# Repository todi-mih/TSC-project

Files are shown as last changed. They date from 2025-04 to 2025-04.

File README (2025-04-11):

Project for E-book made in fusion

Diagrama:
(its in the images folder)

_______
Hardware Modules Overview
ESP32-C6-WROOM-1-N8 – Core Microcontroller
Power Supply: 3.3V
Communication Protocols: SPI, I2C, UART, GPIO
Pin Mapping: Below, each module's interface is connected to the respective microcontroller pins.

USB-C Connector + ESD Protection
Main input for power and data transfer
TVS diodes included for electrostatic discharge (ESD) protection

LiPo Battery Fuel Gauge
Built-In charging controller
IC: MAX17048G+T10 for battery level monitoring
I2C Interface: SCL/SDA for communication with the Battery ChargeLevel IC
Qwiic / Stemma QT Connector for communication via I2C

Reset and Boot Buttons
BOOT: IO9
RESET: EN (Enable)
Reverse polarity protection diodes for safety

LDO Voltage Regulator
Converts 5V to 3.3V, providing power to the ESP32-C6 and connected peripherals

External Flash - NOR Flash 64MB
Connection Type: SPI
FLASH_CS: IO11
Shared SPI Lines: MOSI, MISO, SCK (with SD card and e-paper)

Environmental Sensor - BME688
Protocol: I2C (shared with RTC)
Voltage Supply: 3.3V
Pin Assignments: SDA, SCL

E-Paper Display
Connection Type: SPI
EPD_CS: IO10
EPD_DC: IO5
EPD_RST: IO23
EPD_BUSY: IO3
Shared SPI Lines: MOSI, SCK with SD Card

RTC Module - DS3231SN
Connection Type: I2C
SCL: IO22
SDA: IO21
INT_RTC: IO8
32KHZ: IO1
RTC_RST: IO18

SD Card Interface
Connection Type: SPI
SS_SD: IO4
MOSI: IO7
MISO: IO2
SCK: IO6

SPI Line Protection
Safeguards the SPI communication lines used by external modules like the SD card, e-paper display, and external flash
______

ESP32-C6 PINS
Protocol	ESP32-C6 Assigned Pins		Attached Devices
USB				GPIO13, GPIO12			Power supply & host communication
I2C				GPIO22, GPIO24			Environmental sensor (BME688), RTC, Battery voltage monitor
SPI			  GPIO7, GPIO2, GPIO6		E-paper display, NOR flash memory, SD storage
UART			GPIO16, GPIO17			Debugging / Firmware change
GPIO			GPIO0...GPIO23			Buttons, indicator outputs

BOM , links , datasheets
BUTTON_CUSYOMV1 https://eu.mouser.com/ProductDetail/Omron-Electronics/B3F-1000S?qs=C6KiJco3hx0Z3qfxWTJOrg%3D%3D
https://eu.mouser.com/datasheet/2/307/en_b3f-13826.pdf

100nF capacitor https://store.comet.srl.ro/Catalogue/Product/48939/ https://store.comet.bg/download-file.php?id=11
CPH3225A        https://eu.mouser.com/ProductDetail/Seiko-Semiconductors/CPH3225Aqs=3etwrb1wR%252BhUOph6lAO7eg%3D%3D
https://ro.mouser.com/datasheet/2/360/Seiko_Instruments_MicroBattery_E_20230330_2024Jan_-3561061.pdf
1.7uF capacitor https://store.comet.srl.ro/Catalogue/Product/5163462/ https://store.comet.bg/download-file.php?id=25117
USBLC6-2SC6Y    https://eu.mouser.com/ProductDetail/STMicroelectronics/USBLC6-2SC6Yqs=gNDSiZmRJS%2FOgDexvXkdow%3D%3D
https://ro.mouser.com/datasheet/2/389/usblc6_2sc6y-1852505.pdf
PGB1010603MR    https://eu.mouser.com/ProductDetail/Littelfuse/PGB1010603MR?qs=gu7KAQ731URLg4GSnNNN7Q%3D%3D
https://www.littelfuse.com/assetdocs/pulseguard-esd-suppressors-pgb1-datasheet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
MBR0530         https://eu.mouser.com/ProductDetail/onsemi/MBR0530T3G?qs=3JMERSakebpEmdUS6GetdQ%3D%3D
https://www.littelfuse.com/assetdocs/pulseguard-esd-suppressors-pgb1-datasheet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
TP20R           https://eu.mouser.com/ProductDetail/KOA-Speer/RN73R1ETTP20R0D50?qs=vLWxofP3U2xF4IfSiw9UAw%3D%3D
DS3231SN#       https://eu.mouser.com/ProductDetail/Analog-Devices-Maxim-Integrated/DS3231SN?qs=1eQvB6Dk1vhUlr8%2FOrV0Fw%3D%3D
https://www.koaspeer.com/pdfs/RN73R.pdf
W25Q512JVEIQ    https://eu.mouser.com/ProductDetail/Winbond/W25Q512JVEIQ?qs=l7cgNqFNU1jw6svr3at6tA%3D%3D
https://ro.mouser.com/datasheet/2/949/Winbond_W25Q512JV_Datasheet-3240039.pdf
MAX17048G+T10   https://eu.mouser.com/ProductDetail/Analog-Devices-Maxim-Integrated/MAX17048G%2bT10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
https://ro.mouser.com/datasheet/2/609/MAX17048_MAX17049-3469099.pdf
USBLC6-2SC6Y    https://eu.mouser.com/ProductDetail/STMicroelectronics/USBLC6-2SC6Y?qs=gNDSiZmRJS%2FOgDexvXkdow%3D%3D
https://ro.mouser.com/datasheet/2/389/usblc6_2sc6y-1852505.pdf
DMG2305UX-7     https://eu.mouser.com/ProductDetail/Diodes-Incorporated/DMG2305UX-7?qs=L1DZKBg7t5F%2FNBHrjfxC%252Bg%3D%3D
https://www.diodes.com/assets/Datasheets/DMG2305UX.pdf
XC6220A331MR-G  https://eu.mouser.com/ProductDetail/Torex-Semiconductor/XC6220A331MR-G?qs=AsjdqWjXhJ8ZSWznL1J0gg%3D%3D
https://ro.mouser.com/datasheet/2/760/xc6220-3371556.pdf
SI1308EDL-T1-BE3  https://eu.mouser.com/ProductDetail/Vishay-Siliconix/SI1308EDL-T1-BE3?qs=zW32dvEIR3shhEGZ2ACCcQ%3D%3D
https://www.vishay.com/doc?63399
MCP73831        https://eu.mouser.com/ProductDetail/Microchip-Technology/MCP73831T-2ACI-OT?qs=yUQqVecv4qvbBQBGbHx0Mw%3D%3D
https://ro.mouser.com/datasheet/2/268/MCP73831_Family_Data_Sheet_DS20001984H-3441711.pdf
ESP32-C6-WROOM-1-N8   https://eu.mouser.com/ProductDetail/Espressif-Systems/ESP32-C6-WROOM-1-N8?qs=8Wlm6%252BaMh8ST02Gmwp74cw%3D%3D
https://ro.mouser.com/datasheet/2/891/Espressif_ESP32_C6_WROOM_1__Datasheet_V0_1_PRELIMI-3239987.pdf
BD5229G     https://eu.mouser.com/ProductDetail/ROHM-Semiconductor/BD5229G-1TR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
https://fscdn.rohm.com/en/products/databook/datasheet/ic/power/voltage_detector/bd52xxg-1-e.pdf
FH34SRJ-24S-0.5SH_99_   https://eu.mouser.com/ProductDetail/Hirose-Connector/FH34SRJ-24S-0.5SH50?qs=iyLo5FA4poC8fzWlavnA7A%3D%3D
https://ro.mouser.com/datasheet/2/185/FH34SRJ_24S_0_5SH_50__CL0580_1255_6_50_2DDrawing_0-1615030.pdf
BME688     https://eu.mouser.com/ProductDetail/Bosch-Sensortec/BME688?qs=IS%252B4QmGtzzqQoVDscqwx3A%3D%3D
https://ro.mouser.com/datasheet/2/783/bst_bme688_fl000-2307034.pdf

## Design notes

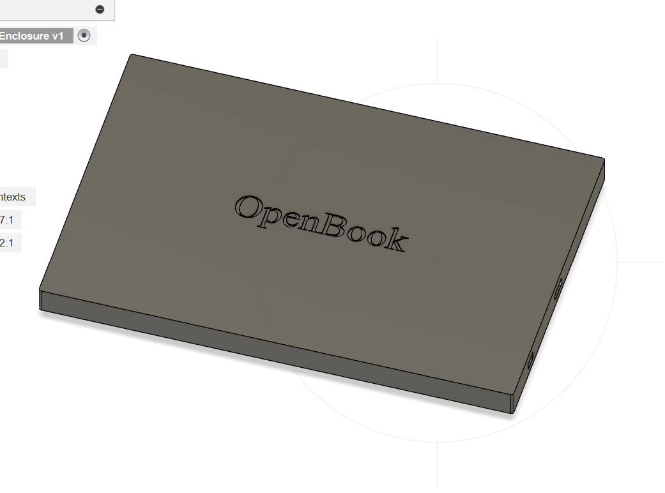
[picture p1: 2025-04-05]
Images/Screenshot 2025-04-05 224908.png

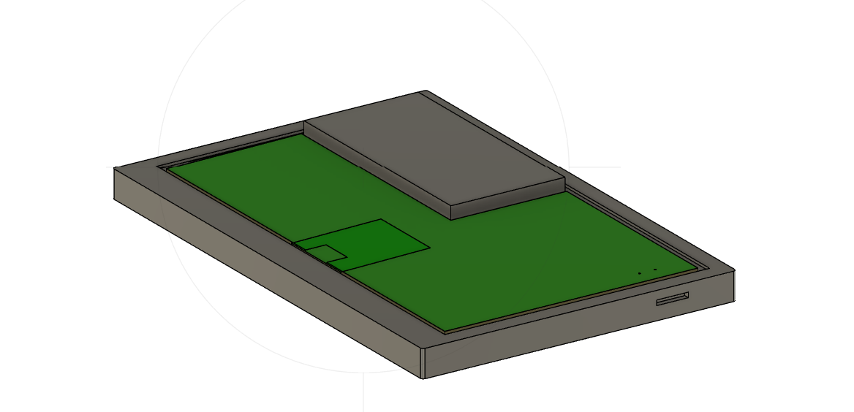
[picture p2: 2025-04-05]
Images/Screenshot 2025-04-05 224919.png

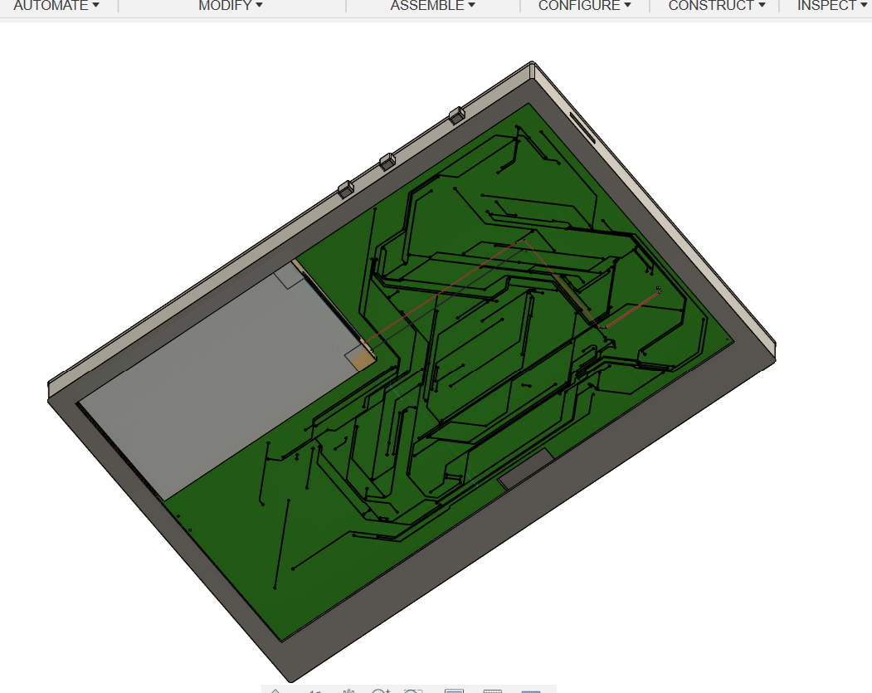
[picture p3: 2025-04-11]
Images/Screenshot 2025-04-11 193749.png

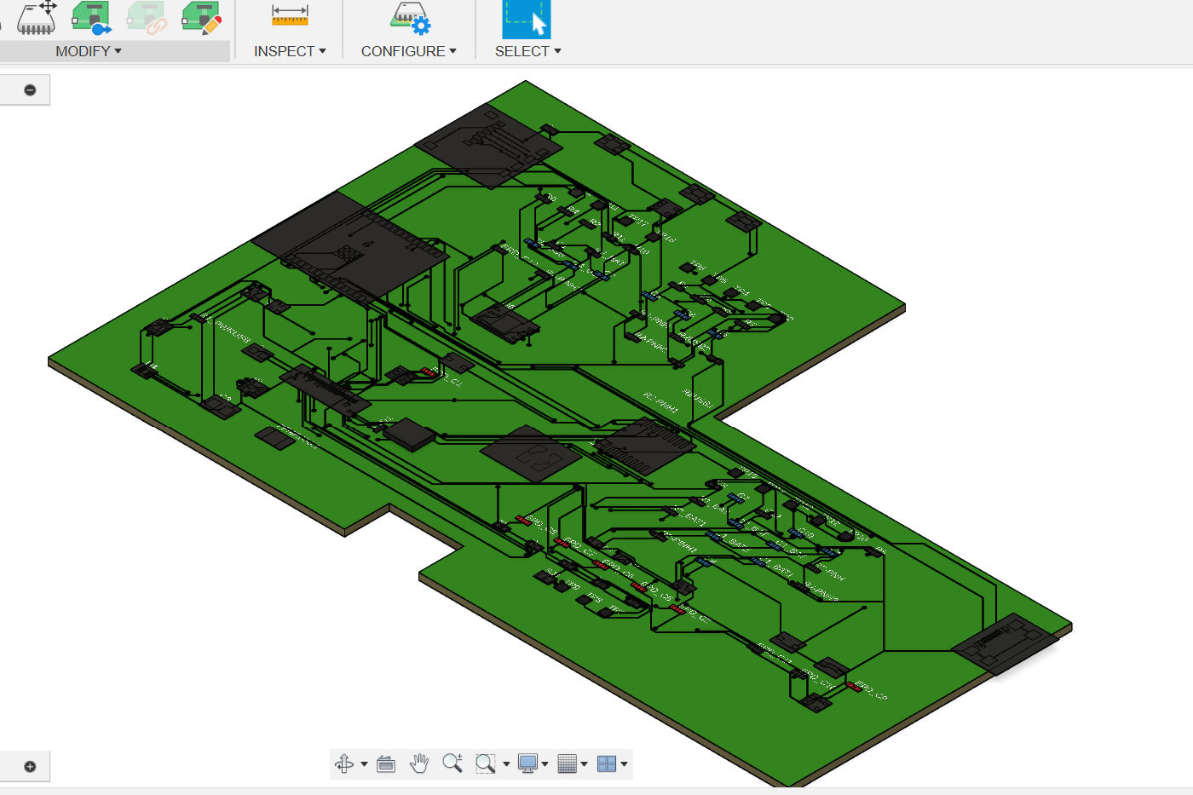
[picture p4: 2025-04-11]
Images/Screenshot 2025-04-11 192457.png

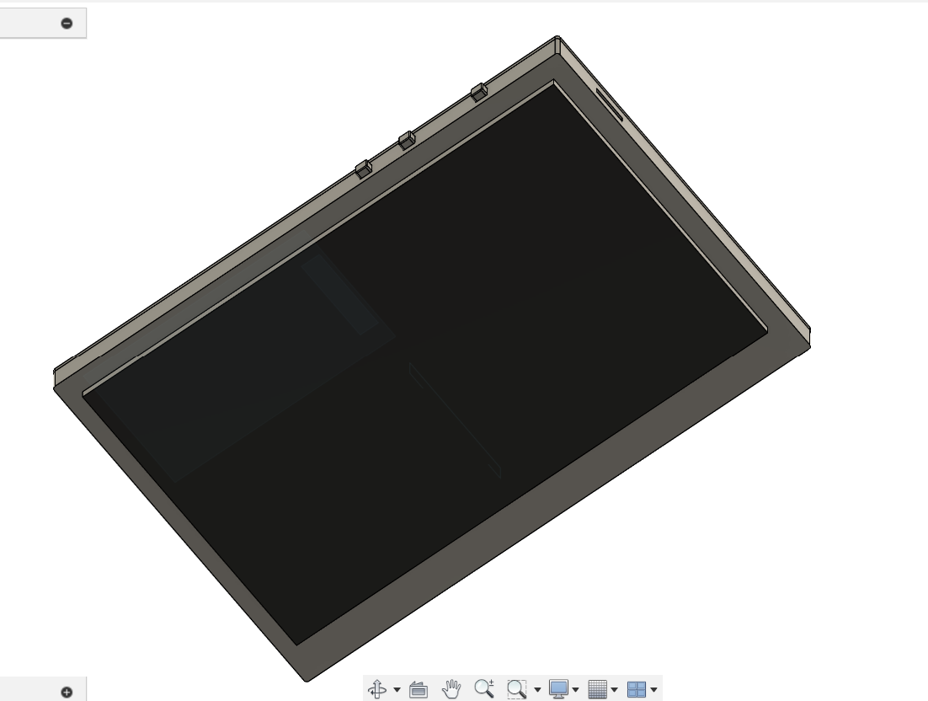
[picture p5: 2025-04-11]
Images/Screenshot 2025-04-11 194323.png

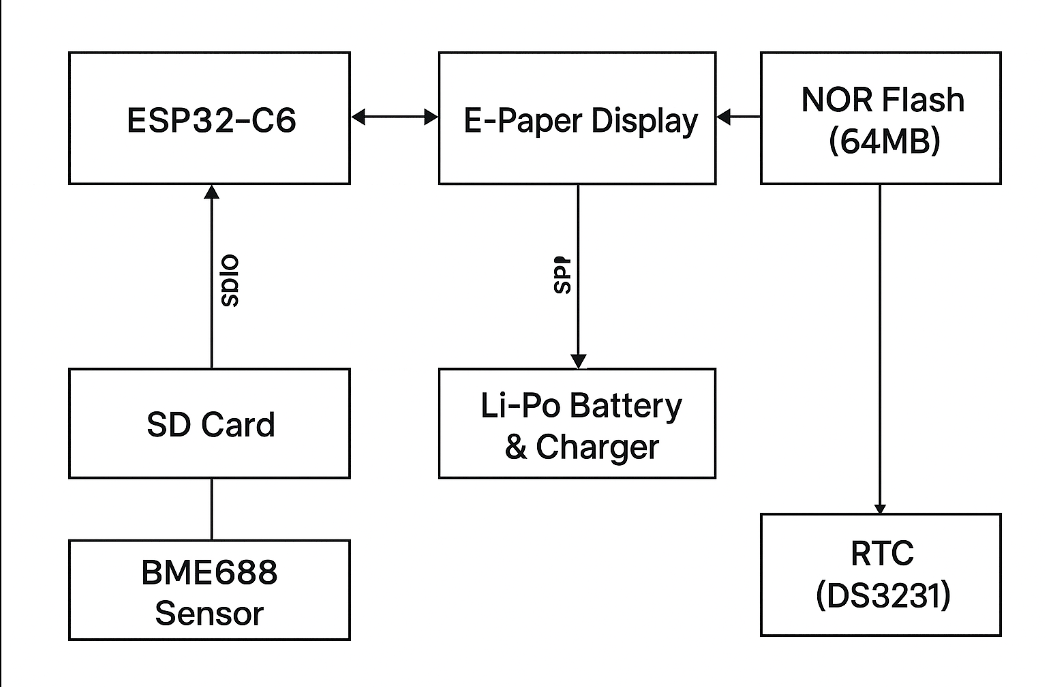
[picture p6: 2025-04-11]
Images/Screenshot 2025-04-11 145103.png

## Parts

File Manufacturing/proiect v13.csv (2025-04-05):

Qty | Value | Device | Package | Parts | Description | ARROW_PART_NUMBER | ARROW_PRICE-STOCK | AVAILABILITY | CENTROID_NOT_SPECIFIED | CHECK_PRICES | COPYRIGHT | DATASHEET | DESCRIPTION | DIGIKEY_DESCRIPTION | DIGIKEY_PART_NUMBER | HEIGHT | LEAD_FREE | MANUFACTURER_NAME | MANUFACTURER_PART_NUMBER | MF | MFR_NAME | MOUSER_PART_NUMBER | MOUSER_PRICE-STOCK | MOUSER_TESTING_PART_NUMBER | MOUSER_TESTING_PRICE-STOCK | MP | MPN | PACKAGE | POPULARITY | PREFIX | PRICE | PROD_ID | PURCHASE-URL | ROHS | SNAPEDA_LINK | SPICEMODEL | SPICEPREFIX | TEMPERATURE_RANGE_HIGH | TEMPERATURE_RANGE_LOW | TP_SIGNAL_NAME | VALUE
1 |  | ADAFRUIT_LEDCHIP-LED0603 | ADAFRUIT_CHIP-LED0603 | LED1 | LED
7 |  | EAGLE-LTSPICE_CC0402 | EAGLE-LTSPICE_C0402 | EPD_C1, EPD_C2, EPD_C5, EPD_C6, EPD_C7, EPD_C8, EPD_C9 | CAPACITOR, European symbol |  |  |  |  |  |  |  |  |  |  |  |  |  |  |  |  |  |  |  |  |  |  |  |  |  |  |  |  |  |  | NONE | C
2 |  | ESP32_WROVER_EAGLE-LTSPICE_CC0402 | ESP32_WROVER_EAGLE-LTSPICE_C0402 | EPD_C10, ERD_C11 | CAPACITOR, European symbol |  |  |  |  |  |  |  |  |  |  |  |  |  |  |  |  |  |  |  |  |  |  |  |  |  |  |  |  |  |  | NONE | C
1 |  | SJ | SJ | SJ1 | SMD solder JUMPER |  |  |  |  |  |  |  |  |  |  |  |  |  |  |  |  |  |  |  |  |  |  |  | 3
1 | 0.47 | ESP32_WROVER_EAGLE-LTSPICE_RR0402 | ESP32_WROVER_EAGLE-LTSPICE_R0402 | R3 | RESISTOR, European symbol |  |  |  |  |  |  |  |  |  |  |  |  |  |  |  |  |  |  |  |  |  |  |  |  |  |  |  |  |  |  | NONE | R
1 | 100 uF TANT | RCL_CPOL-EUCT3528 | RCL_CT3528 | C3 | POLARIZED CAPACITOR, European symbol |  |  |  |  |  |  |  |  |  |  |  |  |  |  |  |  |  |  |  |  |  |  |  | 0 |  |  |  |  |  |  |  | C
3 | 100k | ESP32_WROVER_EAGLE-LTSPICE_RR0402 | ESP32_WROVER_EAGLE-LTSPICE_R0402 | R1_PWRUSB, R2-PINH1, R2-PINH2 | RESISTOR, European symbol |  |  |  |  |  |  |  |  |  |  |  |  |  |  |  |  |  |  |  |  |  |  |  |  |  |  |  |  |  |  | NONE | R
8 | 100nF | EAGLE-LTSPICE_CC0402 | EAGLE-LTSPICE_C0402 | C1, C2, C4_USB, C5, C6, C8, C9, C10 | CAPACITOR, European symbol |  |  |  |  |  |  |  |  |  |  |  |  |  |  |  |  |  |  |  |  |  |  |  |  |  |  |  |  |  |  | NONE | C
1 | 100nF | ESP32_WROVER_EAGLE-LTSPICE_CC0402 | ESP32_WROVER_EAGLE-LTSPICE_C0402 | C12 | CAPACITOR, European symbol |  |  |  |  |  |  |  |  |  |  |  |  |  |  |  |  |  |  |  |  |  |  |  |  |  |  |  |  |  |  | NONE | C
13 | 10k | ESP32_WROVER_EAGLE-LTSPICE_RR0402 | ESP32_WROVER_EAGLE-LTSPICE_R0402 | R1-PNH, R2, R2-PNH, R2-PNH1, R2-PNH2, R2-PNH3, R4, R6, R7, R8, R9, R10, R11 | RESISTOR, European symbol |  |  |  |  |  |  |  |  |  |  |  |  |  |  |  |  |  |  |  |  |  |  |  |  |  |  |  |  |  |  | NONE | R
1 | 10uF | EAGLE-LTSPICE_CC0402 | EAGLE-LTSPICE_C0402 | C7 | CAPACITOR, European symbol |  |  |  |  |  |  |  |  |  |  |  |  |  |  |  |  |  |  |  |  |  |  |  |  |  |  |  |  |  |  | NONE | C
1 | 112A-TAAR-R03_ATTEND | 112A-TAAR-R03_ATTEND | 112ATAARR03ATTEND | J2 | Micro SD Card Socket, Push-Push Type, Top Mount, SMT, H=1.83mm, 10u |  |  |  |  |  |  |  | Micro SD Card Socket | Push-Push Type | Top Mount | SMT | H=1.83mm | 10u |  |  | 1.9mm |  | ATTEND | 112A-TAAR-R03 ATTEND
1 | 15 | ESP32_WROVER_EAGLE-LTSPICE_RR0402 | ESP32_WROVER_EAGLE-LTSPICE_R0402 | R5 | RESISTOR, European symbol |  |  |  |  |  |  |  |  |  |  |  |  |  |  |  |  |  |  |  |  |  |  |  |  |  |  |  |  |  |  | NONE | R
1 | 1uF | ESP32_WROVER_EAGLE-LTSPICE_CC0402 | ESP32_WROVER_EAGLE-LTSPICE_C0402 | ERD_C12 | CAPACITOR, European symbol |  |  |  |  |  |  |  |  |  |  |  |  |  |  |  |  |  |  |  |  |  |  |  |  |  |  |  |  |  |  | NONE | C
1 | 2.2 | ESP32_WROVER_EAGLE-LTSPICE_RR0402 | ESP32_WROVER_EAGLE-LTSPICE_R0402 | R1 | RESISTOR, European symbol |  |  |  |  |  |  |  |  |  |  |  |  |  |  |  |  |  |  |  |  |  |  |  |  |  |  |  |  |  |  | NONE | R
1 | 200 | ESP32_WROVER_EAGLE-LTSPICE_RR0402 | ESP32_WROVER_EAGLE-LTSPICE_R0402 | R1_BAT | RESISTOR, European symbol |  |  |  |  |  |  |  |  |  |  |  |  |  |  |  |  |  |  |  |  |  |  |  |  |  |  |  |  |  |  | NONE | R
2 | 20V/4.2A/52mO/1.4W | ESP32_WROVER_SPARKFUN-DISCRETESEMI_MOSFET_PCH-DMG2305UX-7 | ESP32_WROVER_SPARKFUN-DISCRETESEMI_SOT23-3 | Q1, Q3 | P-channel MOSFETs |  |  |  |  |  |  |  |  |  |  |  |  |  |  |  |  |  |  |  |  |  |  |  |  |  |  | TRAN-14388 |  |  |  |  |  |  |  |  | 20V/4.2A/52mO/1.4W
2 | 2k | ESP32_WROVER_EAGLE-LTSPICE_RR0402 | ESP32_WROVER_EAGLE-LTSPICE_R0402 | R2_BAT, R2_BAT1 | RESISTOR, European symbol |  |  |  |  |  |  |  |  |  |  |  |  |  |  |  |  |  |  |  |  |  |  |  |  |  |  |  |  |  |  | NONE | R
5 | 4.7uF | EAGLE-LTSPICE_CC0402 | EAGLE-LTSPICE_C0402 | C1_BAT, C1_BAT1, C1_BAT2, C2_BAT, C5_USB | CAPACITOR, European symbol |  |  |  |  |  |  |  |  |  |  |  |  |  |  |  |  |  |  |  |  |  |  |  |  |  |  |  |  |  |  | NONE | C
1 | 4.7uF/25V | EAGLE-LTSPICE_CC0402 | EAGLE-LTSPICE_C0402 | C4 | CAPACITOR, European symbol |  |  |  |  |  |  |  |  |  |  |  |  |  |  |  |  |  |  |  |  |  |  |  |  |  |  |  |  |  |  | NONE | C
2 | 5k1 | ESP32_WROVER_EAGLE-LTSPICE_RR0402 | ESP32_WROVER_EAGLE-LTSPICE_R0402 | R2USB1, R2USB2 | RESISTOR, European symbol |  |  |  |  |  |  |  |  |  |  |  |  |  |  |  |  |  |  |  |  |  |  |  |  |  |  |  |  |  |  | NONE | R
1 | 68uH | 744043680IND_4828-WE-TPC_WRE | IND_4828-WE-TPC_WRE | L1 |  |  |  |  |  |  | Copyright (C) 2024 Ultra Librarian. All rights reserved. |  |  |  |  |  |  |  | 744043680 |  | Wurth Electronics
1 | BD5229G-TR | BD5229G-TR | SOT95P280X125-5N | IC2 | Voltage Detector with Adjustable Delay Time: CMOS processes are utilized to develop high precision, low current consumption CMOS reset ICs that allow arbitrary setting of the delay time. The extensive lineup includes both Nch Open Drain and CMOS output types in a wide range of detection voltages (from 2.3V to 6.0V, in 0.1V steps), enabling selection of the ideal solution based on customer requirements. In addition, the entire series is of course both lead-free and RoHS-compliant. |  |  |  |  |  |  |  | Voltage Detector with Adjustable Delay Time: CMOS processes are utilized to develop high precision | low current consumption CMOS reset ICs that allow arbitrary setting of the delay time. The extensive lineup includes both Nch Open Drain and CMOS output types in a wide range of detection voltages (from 2.3V to 6.0V | in 0.1V steps) | enabling selection of the ideal solution based on customer requirements. In addition | the entire series is of course both lead-free and RoHS-compliant. |  |  | 1.25mm |  | ROHM Semiconductor | BD5229G-TR |  |  | 755-BD5229G-TR | https://www.mouser.co.uk/ProductDetail/ROHM-Semiconductor/BD5229G-TR?qs=4kLU8WoGk0vvnhrrYwdszw%3D%3D
3 | BUTTON_CUSYOMV1 | BUTTON_CUSYOMV1 | MYBUTTON | BOOT_BUTTON, CHANGE_BUTTON, RESET_BUTTON
1 | CPH3225A | CPH3225A | CAPCP3225X100N | C11 | Cap 0.011F 3.3V 1210 Flat Check availability |  |  | Not in stock |  | https://www.snapeda.com/parts/CPH3225A/Seiko+Instruments/view-part/?ref=eda |  |  | 11 mF (EDLC) Supercapacitor 3.3 V 1210 (3225 Metric) - - |  |  |  |  |  |  | Seiko Instruments |  |  |  |  |  | CPH3225A |  | 1210 Seiko |  |  | None |  | https://www.snapeda.com/api/url_track_click_mouser/?unipart_id=562593&manufacturer=Seiko Instruments&part_name=CPH3225A&search_term=None |  | https://www.snapeda.com/parts/CPH3225A/Seiko+Instruments/view-part/?ref=snap
1 | DS3231SN# | DS3231SN# | SOIC127P1032X265-16N | U5 | Real Time Clock Serial 16-Pin SOIC W T/R Check availability |  |  | In Stock |  | https://www.snapeda.com/parts/DS3231SN%23/Analog+Devices/view-part/?ref=eda |  |  | Extremely Accurate I²C-Integrated RTC/TCXO/Crystal |  |  |  |  |  |  | Analog Devices |  |  |  |  |  | DS3231SN# |  | SOIC-16 Maxim |  |  | None |  | https://www.snapeda.com/api/url_track_click_mouser/?unipart_id=99048&manufacturer=Analog Devices&part_name=DS3231SN#&search_term=None |  | https://www.snapeda.com/parts/DS3231SN%23/Analog+Devices/view-part/?ref=snap
1 | ESP32-C6-WROOM-1-N8 | ESP32-C6-WROOM-1-N8 | XCVR_ESP32-C6-WROOM-1-N8 | U2 | Check availability |  |  | In Stock |  | https://www.snapeda.com/parts/ESP32-C6-WROOM-1-N8/Espressif+Systems/view-part/?ref=eda |  |  | Multiprotocol Modules ESP32-C6 module | Wi-Fi 6 in 2.4 GHz band | Bluetooth 5 | Zigbee 3.0 and Thread. ESP34-WROOM Compatible - ENGINEERING SAMPLE |  |  |  |  |  |  | Espressif Systems |  |  |  |  |  | ESP32-C6-WROOM-1-N8 |  | None |  |  | None |  |  |  | https://www.snapeda.com/parts/ESP32-C6-WROOM-1-N8/Espressif+Systems/view-part/?ref=snap
1 | ESP32C6_VARISTORCN1812 | ESP32C6_VARISTORCN1812 | ESP32C6_VARISTOR_CT/CN1812 | PFMF.050.1 | VARISTOR |  |  |  |  |  |  |  |  |  |  |  |  |  |  |  |  |  |  |  |  |  |  |  | 0
2 | ESP32_WROVER_AVX---SD0805S020S1R0_AVX_SD0805S020S1R0_0_0AVX_SD0805S020S1R0_0_0 | ESP32_WROVER_AVX---SD0805S020S1R0_AVX_SD0805S020S1R0_0_0AVX_SD0805S020S1R0_0_0 | ESP32_WROVER_AVX---SD0805S020S1R0_AVX_SD0805S020S1R0_0 | D2, D6 | Schottky Barrier Rectifier Diode |  |  |  | No |  |  | http://datasheets.avx.com/schottky.pdf |  | DIODE SCHOTTKY 20V 1A 0805 | 478-7800-1-ND |  | yes |  |  | AVX |  | 581-SD0805S020S1R0 |  |  |  |  |  | 0805 (2012 metric) |  | D |  |  |  | yes |  |  |  | +125°C | -55°C
1 | ESP32_WROVER_BME680_BME680 | ESP32_WROVER_BME680_BME680 | ESP32_WROVER_BME680_PSON80P300X300X100-8N | U3 | Integrated Environmental Unit |  |  | Unavailable |  |  |  |  | Integrated Environmental Unit |  |  |  |  |  |  | Bosch Sensortec |  |  |  |  |  | BME680 |  | LGA-8 Bosch Tools |  |  | None
1 | ESP32_WROVER_SPARKFUN-IC-POWER_MCP73831 | ESP32_WROVER_SPARKFUN-IC-POWER_MCP73831 | ESP32_WROVER_SPARKFUN-IC-POWER_SOT23-5 | U1 | MCP73831T Li-Ion, Li-Pol Controller |  |  |  |  |  |  |  |  |  |  |  |  |  |  |  |  |  |  |  |  |  |  |  |  |  |  | IC-09995
1 | FH34SRJ-24S-0.5SH_99_ | FH34SRJ-24S-0.5SH_99_ | FH34SRJ24S05SH99 | J3 | (0.50mm) Surface Mount, Right Angle |  |  |  |  |  |  |  | 24 Position FFC | FPC Connector Contacts | (0.50mm) Surface Mount | Right Angle |  |  | 1.1mm |  | Hirose | FH34SRJ-24S-0.5SH(99) |  |  | 798-FH34SRJ24S05SH99 | https://www.mouser.co.uk/ProductDetail/Hirose-Connector/FH34SRJ-24S-0.5SH99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
1 | MAX17048G+T10 | MAX17048G+T10 | SON50P200X200X80-9N | U4 | Check availability |  |  | In Stock |  | https://www.snapeda.com/parts/MAX17048G+T10/Analog+Devices/view-part/?ref=eda |  |  | 3µA 1-Cell/2-Cell Fuel Gauge with ModelGauge |  |  |  |  |  |  | Analog Devices |  |  |  |  |  | MAX17048G+T10 |  | TDFN-8 Maxim |  |  | None |  | https://www.snapeda.com/api/url_track_click_mouser/?unipart_id=329239&manufacturer=Analog Devices&part_name=MAX17048G+T10&search_term=None |  | https://www.snapeda.com/parts/MAX17048G+T10/Analog+Devices/view-part/?ref=snap
3 | MBR0530 | MBR0530 | SOD3716X135N | D3, D4, D5 | ON SEMICONDUCTOR - MBR0530 - DIODE, SCHOTTKY, 0.5A, 30V, SOD-123 |  |  | In Stock |  | https://www.snapeda.com/parts/MBR0530/Onsemi/view-part/?ref=eda |  |  | Diode Schottky 30 V 500mA Surface Mount SOD-123 |  |  |  |  |  |  | ON Semiconductor |  |  |  |  |  | MBR0530 |  | SOD-123-2 ON Semiconductor |  |  | None |  | https://www.snapeda.com/api/url_track_click_mouser/?unipart_id=179458&manufacturer=ON Semiconductor&part_name=MBR0530&search_term=None |  | https://www.snapeda.com/parts/MBR0530/Onsemi/view-part/?ref=snap
6 | PGB1010603MR | PGB1010603MR | DIOC1608X36N | D7, D8, D9, D10, D11, D12 | Check availability |  |  | In Stock |  | https://www.snapeda.com/parts/PGB1010603MR/Littelfuse/view-part/?ref=eda |  |  | 150V (Typ) Clamp - Ipp Tvs Diode Surface Mount 0603 (1608 Metric) |  |  |  |  |  |  | Littelfuse Inc. |  |  |  |  |  | PGB1010603MR |  | 0603 Littelfuse Inc. |  |  | None |  | https://www.snapeda.com/api/url_track_click_mouser/?unipart_id=5659453&manufacturer=Littelfuse Inc.&part_name=PGB1010603MR&search_term=None |  | https://www.snapeda.com/parts/PGB1010603MR/Littelfuse/view-part/?ref=snap
1 | QWIIC_RIGHT_ANGLE | QWIIC_CONNECTORJS-1MM | JST04_1MM_RA | J4 | SparkFun I2C Standard Qwiic Connector |  |  |  |  |  |  |  |  |  |  |  |  |  |  |  |  |  |  |  |  |  |  |  |  |  |  | CONN-13694 |  |  |  |  |  |  |  |  | QWIIC_RIGHT_ANGLE
1 | SAMACSYS_PARTS_USB4110-GF-A | SAMACSYS_PARTS_USB4110-GF-A | SAMACSYS_PARTS_USB4110GFA | J1 | CONN USB 2.0 TYPE-C R/A SMT |  |  |  |  |  |  |  | CONN USB 2.0 TYPE-C R/A SMT |  |  | 3.26mm |  | GCT (GLOBAL CONNECTOR TECHNOLOGY) | USB4110-GF-A |  |  | 640-USB4110-GF-A | https://www.mouser.co.uk/ProductDetail/GCT/USB4110-GF-A?qs=KUoIvG%2F9IlYiZvIXQjyJeA%3D%3D
1 | SI1308EDL-T1-GE3 | SI1308EDL-T1-GE3 | SOT65P210X110-3N | Q2 | MOSFET N-Ch 30V 1.5A TrenchFET SC70 Vishay Si1308EDL-T1-GE3 N-channel MOSFET Transistor, 1.5 A, 30 V, 3-Pin SC-70 |  |  | In Stock |  | https://www.snapeda.com/parts/SI1308EDL-T1-GE3/Vishay+Siliconix/view-part/?ref=eda |  |  | Si1308EDL-T1-GE3 N-channel MOSFET Transistor | 1.5 A | 30 V | 3-Pin SC-70 | Siliconix / Vishay SI1308EDL-T1-GE3 |  |  |  |  |  |  | Vishay Siliconix |  |  |  |  |  | SI1308EDL-T1-GE3 |  | SOT-323 Vishay Semiconductor |  |  | None |  | https://www.snapeda.com/api/url_track_click_mouser/?unipart_id=274603&manufacturer=Vishay Siliconix&part_name=SI1308EDL-T1-GE3&search_term=None |  | https://www.snapeda.com/parts/SI1308EDL-T1-GE3/Vishay+Siliconix/view-part/?ref=snap
17 | TPTP20R | TPTP20R | TP20R | TP1, TP2, TP3, TP4, TP5, TP6, TP7, TP8, TP9, TP10, TP11, TP12, TP13, TP14, TP15, TP16, TP17 | Test pad |  |  |  |  |  |  |  |  |  |  |  |  |  |  |  |  |  |  |  |  |  |  |  | 2
1 | USBLC6-2SC6Y | USBLC6-2SC6Y | SOT95P280X145-6N | D1 | Low Cap. ESD Protection Auto SOT-23-6 STMicroelectronics USBLC6-2SC6Y, Dual Uni-Directional TVS Diode Array, 6-Pin SOT-23 |  |  | In Stock |  | https://www.snapeda.com/parts/USBLC6-2SC6Y/STMicroelectronics/view-part/?ref=eda |  |  | 17V Clamp 5A (8/20µs) Ipp Tvs Diode Surface Mount SOT-23-6 |  |  |  |  |  |  | STMicroelectronics |  |  |  |  |  | USBLC6-2SC6Y |  | SOT-23-6 STMicroelectronics |  |  | None |  |  |  | https://www.snapeda.com/parts/USBLC6-2SC6Y/STMicroelectronics/view-part/?ref=snap
1 | W25Q512JVEIQ | W25Q512JVEIQ | SON127P600X800X80-9N | U6 | Check availability |  |  | In Stock |  | https://www.snapeda.com/parts/W25Q512JVEIQ/Winbond+Electronics/view-part/?ref=eda |  |  | FLASH - NOR Memory IC 512Mb (64M x 8) SPI - Quad I/O 133 MHz 8-WSON (8x6) |  |  |  |  |  |  | Winbond Electronics |  |  |  |  |  | W25Q512JVEIQ |  | Package |  |  | None |  |  |  | https://www.snapeda.com/parts/W25Q512JVEIQ/Winbond+Electronics/view-part/?ref=snap
1 | XC6220A331MR-G | XC6220A331MR-G | SOT95P280X120-5N | IC1 | LDO Voltage Regulators |  |  |  |  |  |  |  | LDO Voltage Regulators |  |  | 1.2mm |  | Torex | XC6220A331MR-G |  |  | 865-XC6220A331MR-G | https://www.mouser.co.uk/ProductDetail/Torex-Semiconductor/XC6220A331MR-G?qs=AsjdqWjXhJ8ZSWznL1J0gg%3D%3D

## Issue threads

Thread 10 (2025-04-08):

Missing Via Stitching on PCB

IoanaBoari, 2025-04-08:
Via stitching is not implemented in the PCB design.
Via stitching is important for ensuring continuity between ground planes and for minimizing electromagnetic interference.

- [ ] Please incorporate via stitching where necessary, especially around the ESP32 module.

Labels: PCB, enhancement, design

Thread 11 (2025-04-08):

Traces Routed Under ESP32 Antenna

IoanaBoari, 2025-04-08:
There are traces routed beneath the ESP32 antenna.
The area under the antenna should be cleared to prevent interference with its performance.

- [ ] Please modify the PCB layout to eliminate traces in the antenna zone.

Closed 2025-04-11.

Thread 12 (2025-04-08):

Test Pads Missing Signal Names on Silkscreen

IoanaBoari, 2025-04-08:
The test pads on the PCB do not display the names of the signals they carry on the silkscreen layer, which can make troubleshooting and identification difficult.

- [ ] Please add the appropriate signal names to the test pad silkscreen.

Closed 2025-04-11.

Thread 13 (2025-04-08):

Missing 3D Models for PCB Components

IoanaBoari, 2025-04-08:
The design files do not include 3D models for the PCB components.
Including these models is beneficial for visualizing and validating the overall design.

- [ ] Please integrate the relevant 3D models for all components on the PCB.

Closed 2025-04-11.

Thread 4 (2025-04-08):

Incorrect Naming for ESP32-C6 Pins in Schematic

IoanaBoari, 2025-04-08:
In the schematic, the ESP32-C6 pins are mistakenly labeled as "USR_D-" , "USR_D+", "RTC_RTS" and  instead of the correct "USB_D-", "USB_D+" and "RTC_RST".

- [ ] Please update the pin names to match the hardware specifications.

Closed 2025-04-11.

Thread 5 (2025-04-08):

Missing or incorrect Labels in Schematic

IoanaBoari, 2025-04-08:
Several labels in the schematic are either missing or have incorrect names. This could cause confusion when interpreting the connections.

- [x] Please review and correct all the schematic labels.

Closed 2025-04-11.

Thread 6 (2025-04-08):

Incorrect Power Trace Widths on PCB

IoanaBoari, 2025-04-08:
The power traces on the PCB are currently routed at 0.15mm width, but they should be 0.30mm as per the design requirements.

- [ ] Please adjust the trace widths to ensure proper current handling and safety.

Closed 2025-04-11.

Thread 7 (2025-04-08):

DRC Issues in PCB

IoanaBoari, 2025-04-08:
The DRC check on the PCB has reported the following issues:

- [ ] A SMD-Via track has a via placed under a component (an inductor), which needs to be fixed.
- [ ] SMD components are overlapping with other components.
- [ ] Six "Airwire" errors indicate that some connections remain unrouted.

Please address these issues to guarantee the reliability of the PCB design.

Closed 2025-04-11.

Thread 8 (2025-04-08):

Non-compliant PCB Shape and Dimensions

IoanaBoari, 2025-04-08:
The PCB does not conform to the specified shape and dimensions as defined in the project requirements.
The placement and layout deviate from the given specifications.

- [ ]  Please update the PCB design to meet the required standards.

Labels: PCB, design, bug

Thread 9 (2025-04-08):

Missing Top and Bottom Ground Planes

IoanaBoari, 2025-04-08:
The current PCB layout is missing ground planes on both the top and bottom layers.
Ground planes are crucial for electromagnetic stability and reducing noise.

- [ ] Please add the appropriate ground planes to the PCB design.

Closed 2025-04-11.

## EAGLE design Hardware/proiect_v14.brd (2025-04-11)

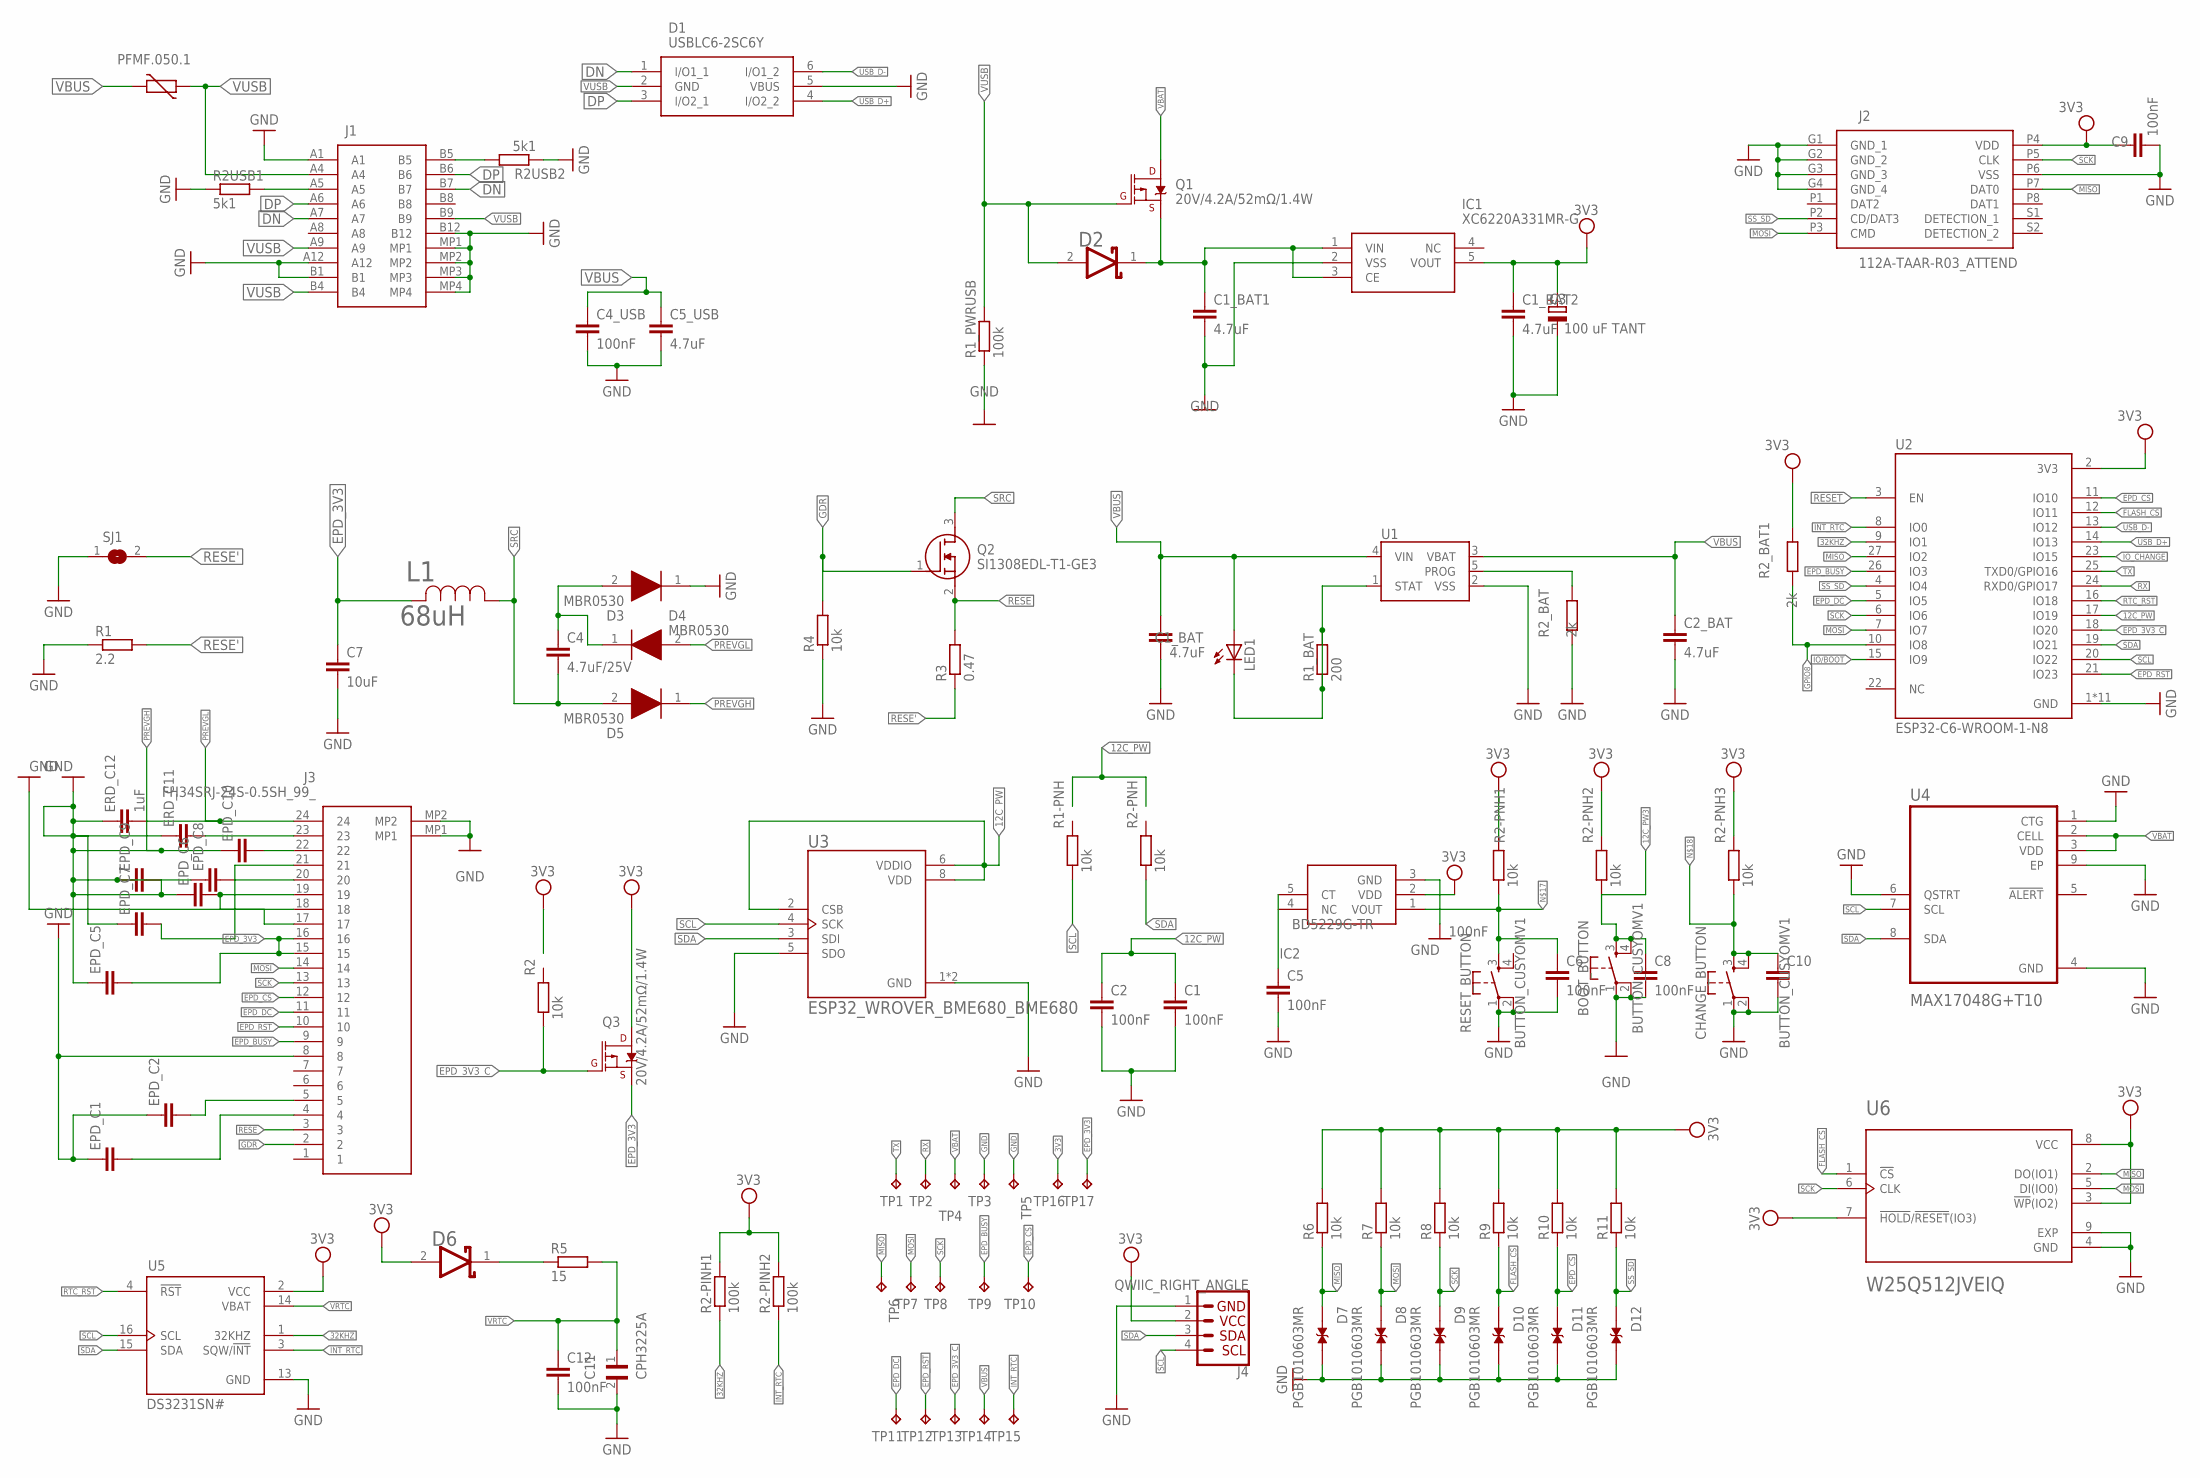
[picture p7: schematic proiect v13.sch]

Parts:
BOOT_BUTTON: BUTTON_CUSYOMV1; MYBUTTON
C1, C2, C4_USB, C5, C6, C8, C9, C10: 100nF; EAGLE-LTSPICE_C0402
C1_BAT, C1_BAT1, C1_BAT2, C2_BAT, C5_USB: 4.7uF; EAGLE-LTSPICE_C0402
C3: 100 uF TANT; RCL_CT3528
C4: 4.7uF/25V; EAGLE-LTSPICE_C0402
C7: 10uF; EAGLE-LTSPICE_C0402
C11: CPH3225A; CAPCP3225X100N
C12: 100nF; ESP32_WROVER_EAGLE-LTSPICE_C0402
CHANGE_BUTTON: BUTTON_CUSYOMV1; MYBUTTON
D1: USBLC6-2SC6Y; SOT95P280X145-6N
D2, D6: ESP32_WROVER_AVX---SD0805S020S1R0_AVX_SD0805S020S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; ESP32_WROVER_AVX---SD0805S020S1R0_AVX_SD0805S020S1R0_0
D3, D4, D5: MBR0530; SOD3716X135N
D7, D8, D9, D10, D11, D12: PGB1010603MR; DIOC1608X36N
EPD_C1, EPD_C2, EPD_C5, EPD_C6, EPD_C7, EPD_C8, EPD_C9: EAGLE-LTSPICE_CC0402; EAGLE-LTSPICE_C0402
EPD_C10: ESP32_WROVER_EAGLE-LTSPICE_CC0402; ESP32_WROVER_EAGLE-LTSPICE_C0402
ERD_C11: ESP32_WROVER_EAGLE-LTSPICE_CC0402; ESP32_WROVER_EAGLE-LTSPICE_C0402
ERD_C12: 1uF; ESP32_WROVER_EAGLE-LTSPICE_C0402
IC1: XC6220A331MR-G; SOT95P280X120-5N
IC2: BD5229G-TR; SOT95P280X125-5N
J1: SAMACSYS_PARTS_USB4110-GF-A; SAMACSYS_PARTS_USB4110GFA
J2: 112A-TAAR-R03_ATTEND; 112ATAARR03ATTEND
J3: FH34SRJ-24S-0.5SH_99_; FH34SRJ24S05SH99
J4: QWIIC_RIGHT_ANGLE; JST04_1MM_RA
L1: 68uH; IND_4828-WE-TPC_WRE
LED1: ADAFRUIT_LEDCHIP-LED0603; ADAFRUIT_CHIP-LED0603
PFMF.050.1: ESP32C6_VARISTORCN1812; ESP32C6_VARISTOR_CT/CN1812
Q1, Q3: 20V/4.2A/52mΩ/1.4W; ESP32_WROVER_SPARKFUN-DISCRETESEMI_SOT23-3
Q2: SI1308EDL-T1-GE3; SOT65P210X110-3N
R1: 2.2; ESP32_WROVER_EAGLE-LTSPICE_R0402
R1-PNH, R2, R2-PNH, R2-PNH1, R2-PNH2, R2-PNH3, R4, R6, R7, R8, R9, R10, R11: 10k; ESP32_WROVER_EAGLE-LTSPICE_R0402
R1_BAT: 200; ESP32_WROVER_EAGLE-LTSPICE_R0402
R1_PWRUSB, R2-PINH1, R2-PINH2: 100k; ESP32_WROVER_EAGLE-LTSPICE_R0402
R2USB1, R2USB2: 5k1; ESP32_WROVER_EAGLE-LTSPICE_R0402
R2_BAT, R2_BAT1: 2k; ESP32_WROVER_EAGLE-LTSPICE_R0402
R3: 0.47; ESP32_WROVER_EAGLE-LTSPICE_R0402
R5: 15; ESP32_WROVER_EAGLE-LTSPICE_R0402
RESET_BUTTON: BUTTON_CUSYOMV1; MYBUTTON
SJ1: SJ
TP1, TP2, TP3, TP4, TP5, TP6, TP7, TP8, TP9, TP10, TP11, TP12, TP13, TP14, TP15, TP16, TP17: TPTP20R; TP20R
U1: ESP32_WROVER_SPARKFUN-IC-POWER_MCP73831; ESP32_WROVER_SPARKFUN-IC-POWER_SOT23-5
U2: ESP32-C6-WROOM-1-N8; XCVR_ESP32-C6-WROOM-1-N8
U3: ESP32_WROVER_BME680_BME680; ESP32_WROVER_BME680_PSON80P300X300X100-8N
U4: MAX17048G+T10; SON50P200X200X80-9N
U5: DS3231SN#; SOIC127P1032X265-16N
U6: W25Q512JVEIQ; SON127P600X800X80-9N

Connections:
3V3: C1_BAT2.1, C3.+, C9.1, D6.2 (ANODE), IC1.5 (VOUT), IC2.2 (VDD), J2.P4 (VDD), J4.2, Q3.3 (D), R2-PINH1.2, R2-PINH2.2, R2-PNH1.2, R2-PNH2.2, R2-PNH3.2, R2_BAT1.2, R6.2, R7.2, R8.2, R9.2, R10.2, R11.2, TP16.TP, U2.2 (3V3), U5.2 (VCC), U6.3 (!WP!(IO2)), U6.7 (!HOLD!/!RESET!(IO3)), U6.8 (VCC)
12C_PW: C1.1, C2.1, U2.17 (IO19), U3.2 (CSB), U3.6 (VDDIO), U3.8 (VDD)
12C_PW1: C5.1, IC2.5 (CT)
12C_PW3: BOOT_BUTTON.3, BOOT_BUTTON.4, C8.1, R2-PNH2.1
32KHZ: R2-PINH1.1, U2.9 (IO1), U5.1 (32KHZ)
DN: J1.A7, J1.B6
DP: J1.A6, J1.B7
EPD_3V3: C7.1, EPD_C5.2, J3.15, J3.16, L1.2, Q3.2 (S), TP17.TP
EPD_3V3_C: Q3.1 (G), R2.1, TP13.TP, U2.18 (IO20)
EPD_BUSY: J3.9, TP9.TP, U2.26 (IO3)
EPD_CS: D11.1, J3.12, R10.1, TP10.TP, U2.11 (IO10)
EPD_DC: J3.11, TP11.TP, U2.5 (IO5)
EPD_RST: J3.10, TP12.TP, U2.21 (IO23)
FLASH_CS: D10.1, R9.1, U2.12 (IO11), U6.1 (!CS)
GDR: J3.2, Q2.1 (G), R4.2
GND: BOOT_BUTTON.1, BOOT_BUTTON.2, C1.2, C1_BAT.2, C1_BAT1.2, C1_BAT2.2, C2.2, C2_BAT.2, C3.-, C4_USB.2, C5.2, C5_USB.2, C6.2, C7.2, C8.2, C9.2, C10.2, C11.2, C12.2, CHANGE_BUTTON.1, CHANGE_BUTTON.2, D1.5 (VBUS), D3.1 (K), D7.2, D8.2, D9.2, D10.2, D11.2, D12.2, EPD_C1.1, EPD_C2.1, IC1.2 (VSS), IC2.3 (GND), J1.A1, J1.A12, J1.B1, J1.B12, J1.MP1, J1.MP2, J1.MP3, J1.MP4, J2.G1 (GND_1), J2.G2 (GND_2), J2.G3 (GND_3), J2.G4 (GND_4), J2.P6 (VSS), J3.8, J3.17, J3.MP1, J3.MP2, J4.1, R1.1, R1_PWRUSB.1, R2USB1.1, R2USB2.1, R2_BAT.1, R4.1, RESET_BUTTON.1, RESET_BUTTON.2, SJ1.1, TP3.TP, TP5.TP, U1.2 (VSS), U2.1 (GND), U2.28 (GND), U2.29_1 (GND), U2.29_2 (GND), U2.29_3 (GND), U2.29_4 (GND), U2.29_5 (GND), U2.29_6 (GND), U2.29_7 (GND), U2.29_8 (GND), U2.29_9 (GND), U3.1 (GND), U3.5 (SDO), U3.7 (GND), U4.1 (CTG), U4.4 (GND), U4.6 (QSTRT), U4.9 (EP), U5.13 (GND), U6.4 (GND), U6.9 (EXP)
GPIO8: R2_BAT1.1, U2.10 (IO8)
INT_RTC: R2-PINH2.1, TP15.TP, U2.8 (IO0), U5.3 (SQW/!INT)
IO/BOOT: U2.15 (IO9)
IO_CHANGE: U2.23 (IO15)
MISO: D7.1, J2.P7 (DAT0), R6.1, TP6.TP, U2.27 (IO2), U6.2 (DO(IO1))
MOSI: D8.1, J2.P3 (CMD), J3.14, R7.1, TP7.TP, U2.7 (IO7), U6.5 (DI(IO0))
unnamed: J1.A5, R2USB1.2
unnamed: J1.B5, R2USB2.2
unnamed: C4_USB.1, C5_USB.1
unnamed: C1_BAT1.1, D2.1 (CATHODE), IC1.1 (VIN), IC1.3 (CE), Q1.2 (S)
unnamed: D2.2 (ANODE), Q1.1 (G), R1_PWRUSB.2
unnamed: R2_BAT.2, U1.5 (PROG)
unnamed: C4.1, D3.2 (A), D4.1 (K)
unnamed: EPD_C1.2, J3.4
unnamed: EPD_C2.2, J3.5
unnamed: C6.1, IC2.1 (VOUT), R2-PNH1.1, RESET_BUTTON.3
unnamed: C10.1, CHANGE_BUTTON.3, CHANGE_BUTTON.4, R2-PNH3.1
unnamed: D6.1 (CATHODE), R5.1
unnamed: EPD_C8.2, J3.20
unnamed: EPD_C7.2, J3.21
unnamed: EPD_C6.2, J3.18, J3.19
unnamed: EPD_C10.2, J3.22
unnamed: ERD_C11.2, J3.23
PREVGH: D5.1 (K), EPD_C5.1, EPD_C6.1, EPD_C7.1, EPD_C8.1, EPD_C9.1, EPD_C9.2, EPD_C10.1, ERD_C11.1, ERD_C12.1
PREVGL: D4.2 (A), ERD_C12.2, J3.24
RESE: J3.3, Q2.2 (S), R3.2
RESE': R1.2, R3.1, SJ1.2
RESE'1: LED1.C, R1_BAT.1, R1_BAT.2, U1.1 (STAT)
RESET: U2.3 (EN)
RX: TP2.TP, U2.24 (RXD0/GPIO17)
SCK: D9.1, J2.P5 (CLK), J3.13, R8.1, TP8.TP, U2.6 (IO6), U6.6 (CLK)
SCL: J4.4, R1-PNH.1, U2.20 (IO22), U3.4 (SCK), U4.7 (SCL), U5.16 (SCL)
SDA: J4.3, R2-PNH.1, U2.19 (IO21), U3.3 (SDI), U4.8 (SDA), U5.15 (SDA)
SRC: C4.2, D5.2 (A), L1.1, Q2.3 (D)
SS_SD: D12.1, J2.P2 (CD/DAT3), R11.1, U2.4 (IO4)
TX: TP1.TP, U2.25 (TXD0/GPIO16)
VBAT: Q1.3 (D), TP4.TP, U4.2 (CELL), U4.3 (VDD)
VBUS: C1_BAT.1, C2_BAT.1, LED1.A, TP14.TP, U1.3 (VBAT), U1.4 (VIN)
VRTC: C11.1, C12.1, R5.2, U5.14 (VBAT)
VUSB: J1.A4, PFMF.050.1.1

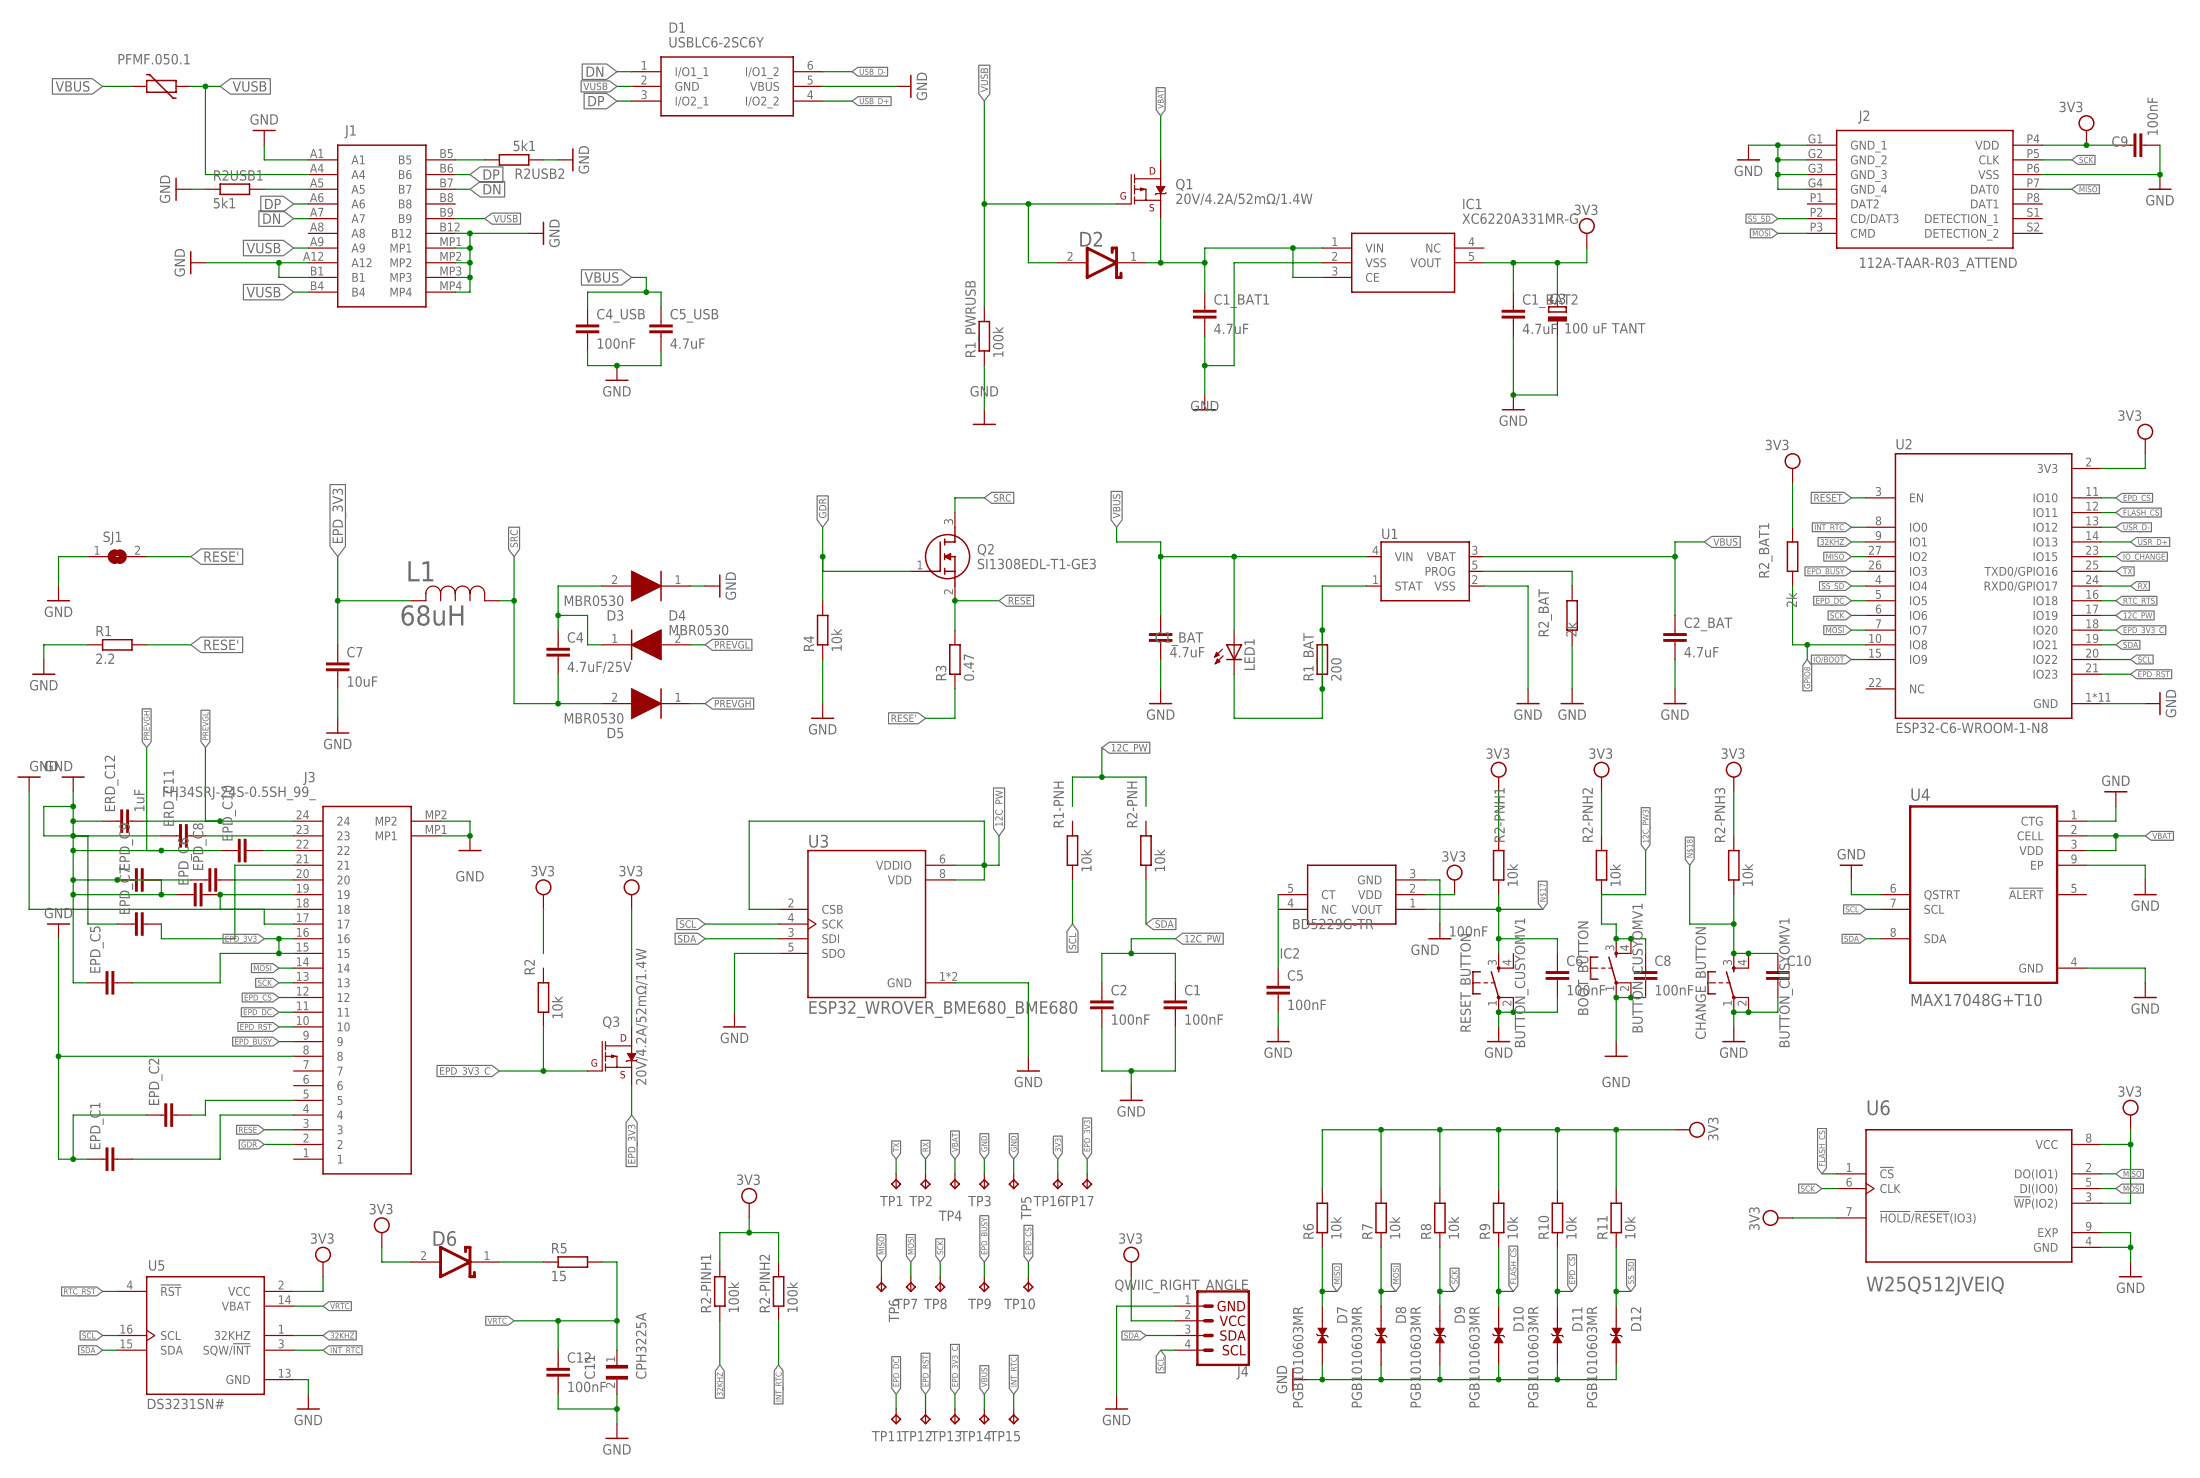
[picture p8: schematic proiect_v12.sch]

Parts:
BOOT_BUTTON: BUTTON_CUSYOMV1; MYBUTTON
C1, C2, C4_USB, C5, C6, C8, C9, C10: 100nF; EAGLE-LTSPICE_C0402
C1_BAT, C1_BAT1, C1_BAT2, C2_BAT, C5_USB: 4.7uF; EAGLE-LTSPICE_C0402
C3: 100 uF TANT; RCL_CT3528
C4: 4.7uF/25V; EAGLE-LTSPICE_C0402
C7: 10uF; EAGLE-LTSPICE_C0402
C11: CPH3225A; CAPCP3225X100N
C12: 100nF; ESP32_WROVER_EAGLE-LTSPICE_C0402
CHANGE_BUTTON: BUTTON_CUSYOMV1; MYBUTTON
D1: USBLC6-2SC6Y; SOT95P280X145-6N
D2, D6: ESP32_WROVER_AVX---SD0805S020S1R0_AVX_SD0805S020S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; ESP32_WROVER_AVX---SD0805S020S1R0_AVX_SD0805S020S1R0_0
D3, D4, D5: MBR0530; SOD3716X135N
D7, D8, D9, D10, D11, D12: PGB1010603MR; DIOC1608X36N
EPD_C1, EPD_C2, EPD_C5, EPD_C6, EPD_C7, EPD_C8, EPD_C9: EAGLE-LTSPICE_CC0402; EAGLE-LTSPICE_C0402
EPD_C10: ESP32_WROVER_EAGLE-LTSPICE_CC0402; ESP32_WROVER_EAGLE-LTSPICE_C0402
ERD_C11: ESP32_WROVER_EAGLE-LTSPICE_CC0402; ESP32_WROVER_EAGLE-LTSPICE_C0402
ERD_C12: 1uF; ESP32_WROVER_EAGLE-LTSPICE_C0402
IC1: XC6220A331MR-G; SOT95P280X120-5N
IC2: BD5229G-TR; SOT95P280X125-5N
J1: SAMACSYS_PARTS_USB4110-GF-A; SAMACSYS_PARTS_USB4110GFA
J2: 112A-TAAR-R03_ATTEND; 112ATAARR03ATTEND
J3: FH34SRJ-24S-0.5SH_99_; FH34SRJ24S05SH99
J4: QWIIC_RIGHT_ANGLE; JST04_1MM_RA
L1: 68uH; IND_4828-WE-TPC_WRE
LED1: ADAFRUIT_LEDCHIP-LED0603; ADAFRUIT_CHIP-LED0603
PFMF.050.1: ESP32C6_VARISTORCN1812; ESP32C6_VARISTOR_CT/CN1812
Q1, Q3: 20V/4.2A/52mΩ/1.4W; ESP32_WROVER_SPARKFUN-DISCRETESEMI_SOT23-3
Q2: SI1308EDL-T1-GE3; SOT65P210X110-3N
R1: 2.2; ESP32_WROVER_EAGLE-LTSPICE_R0402
R1-PNH, R2, R2-PNH, R2-PNH1, R2-PNH2, R2-PNH3, R4, R6, R7, R8, R9, R10, R11: 10k; ESP32_WROVER_EAGLE-LTSPICE_R0402
R1_BAT: 200; ESP32_WROVER_EAGLE-LTSPICE_R0402
R1_PWRUSB, R2-PINH1, R2-PINH2: 100k; ESP32_WROVER_EAGLE-LTSPICE_R0402
R2USB1, R2USB2: 5k1; ESP32_WROVER_EAGLE-LTSPICE_R0402
R2_BAT, R2_BAT1: 2k; ESP32_WROVER_EAGLE-LTSPICE_R0402
R3: 0.47; ESP32_WROVER_EAGLE-LTSPICE_R0402
R5: 15; ESP32_WROVER_EAGLE-LTSPICE_R0402
RESET_BUTTON: BUTTON_CUSYOMV1; MYBUTTON
SJ1: SJ
TP1, TP2, TP3, TP4, TP5, TP6, TP7, TP8, TP9, TP10, TP11, TP12, TP13, TP14, TP15, TP16, TP17: TPTP20R; TP20R
U1: ESP32_WROVER_SPARKFUN-IC-POWER_MCP73831; ESP32_WROVER_SPARKFUN-IC-POWER_SOT23-5
U2: ESP32-C6-WROOM-1-N8; XCVR_ESP32-C6-WROOM-1-N8
U3: ESP32_WROVER_BME680_BME680; ESP32_WROVER_BME680_PSON80P300X300X100-8N
U4: MAX17048G+T10; SON50P200X200X80-9N
U5: DS3231SN#; SOIC127P1032X265-16N
U6: W25Q512JVEIQ; SON127P600X800X80-9N

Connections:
3V3: C1_BAT2.1, C3.+, C9.1, D6.2 (ANODE), IC1.5 (VOUT), IC2.2 (VDD), J2.P4 (VDD), J4.2, Q3.3 (D), R2-PINH1.2, R2-PINH2.2, R2-PNH1.2, R2-PNH2.2, R2-PNH3.2, R2_BAT1.2, R6.2, R7.2, R8.2, R9.2, R10.2, R11.2, TP16.TP, U2.2 (3V3), U5.2 (VCC), U6.3 (!WP!(IO2)), U6.7 (!HOLD!/!RESET!(IO3)), U6.8 (VCC)
12C_PW: C1.1, C2.1, U2.17 (IO19), U3.2 (CSB), U3.6 (VDDIO), U3.8 (VDD)
12C_PW1: C5.1, IC2.5 (CT)
12C_PW3: BOOT_BUTTON.3, BOOT_BUTTON.4, C8.1, R2-PNH2.1
32KHZ: R2-PINH1.1, U2.9 (IO1), U5.1 (32KHZ)
DN: J1.A7, J1.B6
DP: J1.A6, J1.B7
EPD_3V3: C7.1, EPD_C5.2, J3.15, J3.16, L1.2, Q3.2 (S), TP17.TP
EPD_3V3_C: Q3.1 (G), R2.1, TP13.TP, U2.18 (IO20)
EPD_BUSY: J3.9, TP9.TP, U2.26 (IO3)
EPD_CS: D11.1, J3.12, R10.1, TP10.TP, U2.11 (IO10)
EPD_DC: J3.11, TP11.TP, U2.5 (IO5)
EPD_RST: J3.10, TP12.TP, U2.21 (IO23)
FLASH_CS: D10.1, R9.1, U2.12 (IO11), U6.1 (!CS)
GDR: J3.2, Q2.1 (G), R4.2
GND: BOOT_BUTTON.1, BOOT_BUTTON.2, C1.2, C1_BAT.2, C1_BAT1.2, C1_BAT2.2, C2.2, C2_BAT.2, C3.-, C4_USB.2, C5.2, C5_USB.2, C6.2, C7.2, C8.2, C9.2, C10.2, C11.2, C12.2, CHANGE_BUTTON.1, CHANGE_BUTTON.2, D1.5 (VBUS), D3.1 (K), D7.2, D8.2, D9.2, D10.2, D11.2, D12.2, EPD_C1.1, EPD_C2.1, IC1.2 (VSS), IC2.3 (GND), J1.A1, J1.A12, J1.B1, J1.B12, J1.MP1, J1.MP2, J1.MP3, J1.MP4, J2.G1 (GND_1), J2.G2 (GND_2), J2.G3 (GND_3), J2.G4 (GND_4), J2.P6 (VSS), J3.8, J3.17, J3.MP1, J3.MP2, J4.1, R1.1, R1_PWRUSB.1, R2USB1.1, R2USB2.1, R2_BAT.1, R4.1, RESET_BUTTON.1, RESET_BUTTON.2, SJ1.1, TP3.TP, TP5.TP, U1.2 (VSS), U2.1 (GND), U2.28 (GND), U2.29_1 (GND), U2.29_2 (GND), U2.29_3 (GND), U2.29_4 (GND), U2.29_5 (GND), U2.29_6 (GND), U2.29_7 (GND), U2.29_8 (GND), U2.29_9 (GND), U3.1 (GND), U3.5 (SDO), U3.7 (GND), U4.1 (CTG), U4.4 (GND), U4.6 (QSTRT), U4.9 (EP), U5.13 (GND), U6.4 (GND), U6.9 (EXP)
GPIO8: R2_BAT1.1, U2.10 (IO8)
INT_RTC: R2-PINH2.1, TP15.TP, U2.8 (IO0), U5.3 (SQW/!INT)
IO/BOOT: U2.15 (IO9)
IO_CHANGE: U2.23 (IO15)
MISO: D7.1, J2.P7 (DAT0), R6.1, TP6.TP, U2.27 (IO2), U6.2 (DO(IO1))
MOSI: D8.1, J2.P3 (CMD), J3.14, R7.1, TP7.TP, U2.7 (IO7), U6.5 (DI(IO0))
unnamed: J1.A5, R2USB1.2
unnamed: J1.B5, R2USB2.2
unnamed: C4_USB.1, C5_USB.1
unnamed: C1_BAT1.1, D2.1 (CATHODE), IC1.1 (VIN), IC1.3 (CE), Q1.2 (S)
unnamed: D2.2 (ANODE), Q1.1 (G), R1_PWRUSB.2
unnamed: R2_BAT.2, U1.5 (PROG)
unnamed: C4.1, D3.2 (A), D4.1 (K)
unnamed: EPD_C1.2, J3.4
unnamed: EPD_C2.2, J3.5
unnamed: C6.1, IC2.1 (VOUT), R2-PNH1.1, RESET_BUTTON.3
unnamed: C10.1, CHANGE_BUTTON.3, CHANGE_BUTTON.4, R2-PNH3.1
unnamed: D6.1 (CATHODE), R5.1
unnamed: EPD_C8.2, J3.20
unnamed: EPD_C7.2, J3.21
unnamed: EPD_C6.2, J3.18, J3.19
unnamed: EPD_C10.2, J3.22
unnamed: ERD_C11.2, J3.23
PREVGH: D5.1 (K), EPD_C5.1, EPD_C6.1, EPD_C7.1, EPD_C8.1, EPD_C9.1, EPD_C9.2, EPD_C10.1, ERD_C11.1, ERD_C12.1
PREVGL: D4.2 (A), ERD_C12.2, J3.24
RESE: J3.3, Q2.2 (S), R3.2
RESE': R1.2, R3.1, SJ1.2
RESE'1: LED1.C, R1_BAT.1, R1_BAT.2, U1.1 (STAT)
RESET: U2.3 (EN)
RX: TP2.TP, U2.24 (RXD0/GPIO17)
SCK: D9.1, J2.P5 (CLK), J3.13, R8.1, TP8.TP, U2.6 (IO6), U6.6 (CLK)
SCL: J4.4, R1-PNH.1, U2.20 (IO22), U3.4 (SCK), U4.7 (SCL), U5.16 (SCL)
SDA: J4.3, R2-PNH.1, U2.19 (IO21), U3.3 (SDI), U4.8 (SDA), U5.15 (SDA)
SRC: C4.2, D5.2 (A), L1.1, Q2.3 (D)
SS_SD: D12.1, J2.P2 (CD/DAT3), R11.1, U2.4 (IO4)
TX: TP1.TP, U2.25 (TXD0/GPIO16)
VBAT: Q1.3 (D), TP4.TP, U4.2 (CELL), U4.3 (VDD)
VBUS: C1_BAT.1, C2_BAT.1, LED1.A, TP14.TP, U1.3 (VBAT), U1.4 (VIN)
VRTC: C11.1, C12.1, R5.2, U5.14 (VBAT)
VUSB: J1.A4, PFMF.050.1.1

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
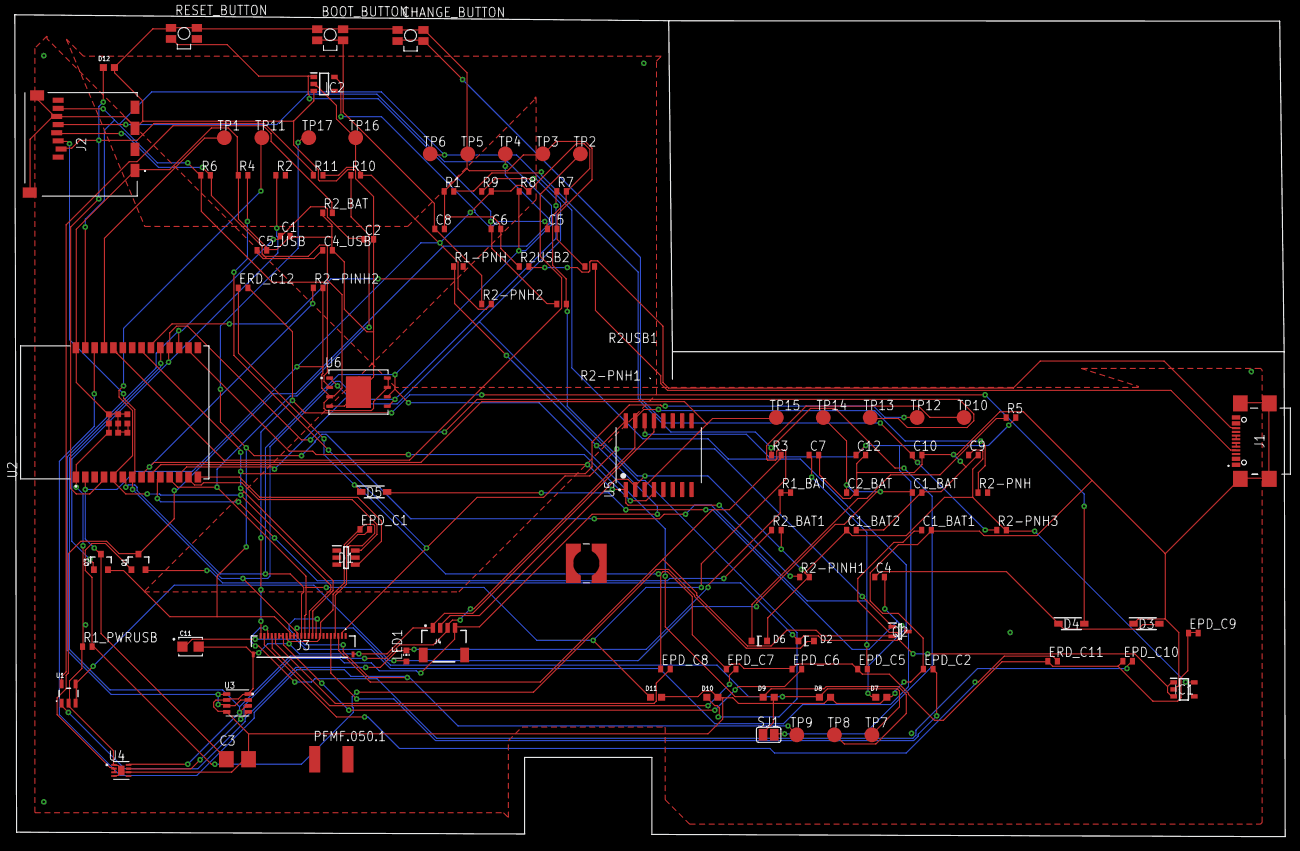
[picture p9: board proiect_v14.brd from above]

Board: 2 copper layers, 171.9 x 111.2 mm, 103 parts (0 on the bottom side), 56 nets.

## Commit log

2025-04-05 Final commit - ready for public
    [PnP_proiect v13_front.csv, proiect v13.csv, proiect_v12.sch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]
2025-04-11 Add files via upload
    new fixed scheme
    [proiect v13.sch]
2025-04-11 Add files via upload
    improved pcb
    [proiect_v13.brd]
2025-04-11 Add files via upload
    new photos of improved boards
2025-04-11 Add files via upload
    fixed .step file and .step file for the pcb
2025-04-11 Add files via upload
    Added GND planes and via switching
    [proiect_v14.brd]

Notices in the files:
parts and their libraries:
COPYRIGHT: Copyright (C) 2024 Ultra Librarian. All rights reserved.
